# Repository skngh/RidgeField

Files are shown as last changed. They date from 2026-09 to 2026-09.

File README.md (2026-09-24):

# Ridge Field

Fully wireless guitar pedal. A small box mounts on the guitar and sends its knobs, joystick and light sensor over Bluetooth to the pedal on the floor, which runs everything and does processing through a Daisy Seed.

**[Full video walking through the pedal!](https://youtu.be/8Uf5aeJEN9k)**

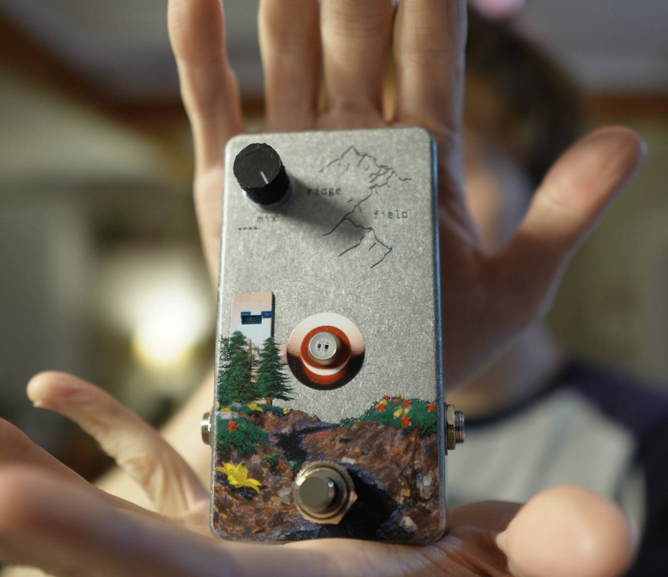
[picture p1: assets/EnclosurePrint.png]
Ridge Field pedal


Everything here is free to use!! Please let me know if you make anything with something here, I'd really love to see :)

## Contents

- [`hardware/`](hardware/): KiCad projects for both boards, custom libraries, and ready-to-order PCBWay files
- [`firmware/`](firmware/): all the code
  - [`firmware/daisy/`](firmware/daisy/): the audio DSP running on the Daisy Seed in the pedal
  - [`firmware/ESP32C3/`](firmware/ESP32C3/): the Bluetooth link (guitar-side server and pedal-side client)
- [`enclosure/`](enclosure/): FreeCAD models, STLs, and the Tayda drill template

## How it works

There are two units:

- **Server (on the guitar):** a XIAO ESP32-C3 reads the two knobs, an LDR (light sensor) and a joystick, then sends any changes over BLE. It runs off a Li-ion battery.
- **Main/Client (the pedal):** a second XIAO ESP32-C3 connects to the server and passes the control values to a Daisy Seed over UART. Then the Daisy does all the audio processing.

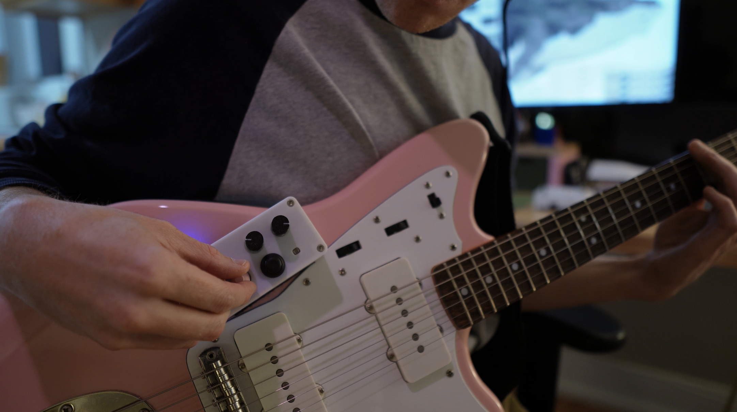
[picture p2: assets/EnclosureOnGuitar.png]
On the guitar


## Controls

| Control | What it does |
| --- | --- |
| Knob 1 | Delay time |
| Knob 2 | Delay feedback (fully down turns the delay off) |
| LDR | Reverb. Cover it with your hand for more |
| Joystick X | Pitch shift, an octave up or down depending on direction |
| Joystick Y | Bitcrusher. One direction lowers bit depth, the other lowers sample rate |
| Button press | Latch the current joystick position |
| Button hold | LDR calibration, see below |
| Mix knob (pedal) | Dry/wet |
| Footswitch (pedal) | Bypass |

**LDR calibration:** hold the joystick button. For the first few seconds leave the LDR uncovered. Once the LED starts blinking fast, cover it and keep holding until the LED goes back to normal (~7 s total). The pedal saves the calibration so it survives next time you unplug and replug.

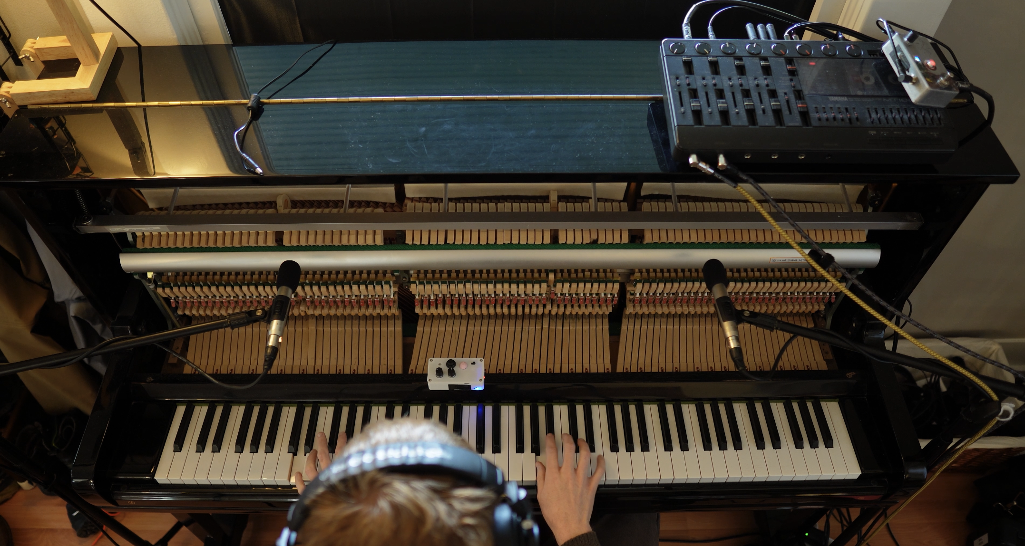
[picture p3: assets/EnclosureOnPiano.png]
On the piano


## Building one

Rough order:

1. **PCBs:** order the 2 pcbs located in [`hardware/PCBWayFiles`](hardware/PCBWayFiles/) (Gerbers, BOM and pick-and-place are all there).
2. **Server Enclosure:** 3D print the parts in [`enclosure/STL files`](enclosure/STL%20files/). Uses [M3x6mm screws](https://www.amazon.com/dp/B0DJQG5YLF?ref_=ppx_hzsearch_conn_dt_b_fed_asin_title_2) and [M3 heat inserts](https://www.amazon.com/dp/B08BCRZZS3).
3. **Main Enclosure:** the main enclosure is a 1590B pedal. I used [Tayda Electronics](https://www.taydaelectronics.com/1590b-style-aluminum-diecast-enclosure.html) for mine so I could order it fully drilled and with a UV print. Here's the [Tayda drill template](enclosure/Tayda_Drill_Schematic.txt).
4. **Firmware:** flash both ESP32-C3s from [`firmware/ESP32C3`](firmware/ESP32C3/), then build and flash the Daisy from [`firmware/daisy`](firmware/daisy/).

See each folder's README for more details.

## The artwork

I got the art on the enclosure UV printed through Tayda. The art isn't included in this repo, but here's how I did it in Blender!

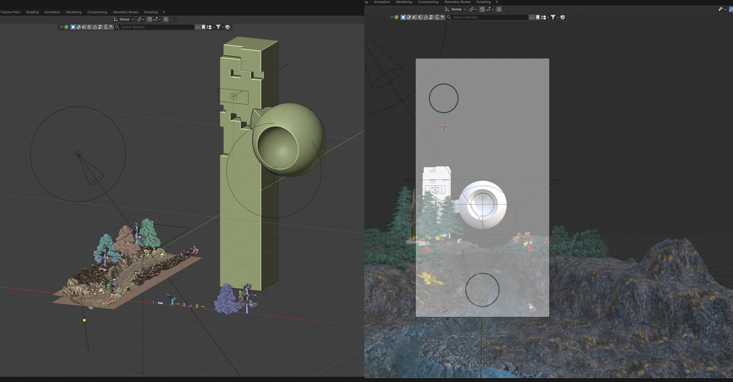
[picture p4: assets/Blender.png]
Blender scene


You can attach an image as a background to a camera in Blender. So I took the drill schematic coords and made an illustrator file showing the holes that I added as the background. Then I could easily place objects in the scene and it would line up later with the pedal (for some reason the bluetooth LED on the left didn't line up perfectly, so I think I must've gotten the coords off a tiny bit).

I have a video [here](https://www.youtube.com/watch?v=Ckmy4d0Q_N0&t=555s) showing how to make designs for Tayda's UV printing service.

## Clone it

The DSP library I used is a git submodule, so clone with:

```sh
git clone --recursive https://github.com/skngh/RidgeField.git
# if you already cloned it:
git submodule update --init
```

## Caveats

As I mentioned in the video, I am actually planning on making a V2 of the main pedal PCB going forward. It is fully functioning, but you can hear some of the data transfers as these consistent beeps going, and I'm an idiot who didn't add a LPF to the output buffer, so there's lots of high frequency noise. It's far above the range of human hearing, but I had this issue in the past where some annoying looper pedal folded that range down and caused all this aliasing (at least I think that's what happened), so I plan on making the board 4 layers and then adding a LPF across the output buffer's op amp. Relatively easy, but in order to test I'd have to reorder the boards and I don't really wanna spend that money right now :o

## Built with

- [Daisy Seed](https://electro-smith.com/products/daisy-seed) + [libDaisy](https://github.com/electro-smith/libDaisy) / [DaisySP](https://github.com/electro-smith/DaisySP)
- [Seeed XIAO ESP32-C3](https://wiki.seeedstudio.com/XIAO_ESP32C3_Getting_Started/)
- [NimBLE-Arduino](https://github.com/h2zero/NimBLE-Arduino)
- My [Simple-DSP](https://github.com/skngh/Simple-DSP) library
- KiCad 10.0, FreeCAD 1.1, Blender

## License

[MIT](LICENSE). Do whatever you want with it!

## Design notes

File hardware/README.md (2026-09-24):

# Hardware

Made with **KiCad 10.0**. Older versions won't open these files.

- [`BluetoothPedal_Main/`](BluetoothPedal_Main/): the main pedal board. Includes the Daisy, XIAO ESP32-C3, input/output buffers, DC power, footswitch and mix knob.
- [`BluetoothPedal_Server/`](BluetoothPedal_Server/): the guitar-mounted board. XIAO ESP32-C3, MCP3208 ADC, knobs, LDR, joystick, battery.
- [`libs/`](libs/): custom symbols, footprints and 3D models used by both projects
- [`PCBWayFiles/`](PCBWayFiles/): Gerbers, BOM and pick-and-place (`-all-pos.csv`) for each board. If you just want boards, these are all you need.

## Opening the projects

I think both projects should open and look right without any setup? But if you want to edit or update parts you may need to do these steps below:

- **Footprints:** each project has an `fp-lib-table` pointing to `../libs/footprints/Custom_Footprints.pretty`. This originally was an absolute path that I changed, but I'm not totally positive that works so you may need to change it, idk.
- **Symbols:** `custom_symbols` and `Seeed_Studio_XIAO_Series` aren't registered in a project symbol table. If you need them, add `libs/symbols/*.kicad_sym` under _Preferences → Manage Symbol Libraries → Project Specific Libraries_.
- **3D models:** some models seem to be absolute paths from my computer, so you may need to configure them in each footprint's settings.

None of this affects the Gerbers, those should all work fine.

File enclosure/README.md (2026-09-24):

# Enclosure

Models made with **FreeCAD 1.1**.

- [`FreeCAD files/`](FreeCAD%20files/): source models for the Main and Server enclosures, knob cap and joystick cap
- [`STL files/`](STL%20files/): ready to print
  - `Server/`: body and lid for the guitar mounted box
  - `Main/`: body and lid for the Main pedal box. I used this to make sure my drill schematic worked, and to mockup the UV print, so I just figured I'd include it.
  - `Knob/`: knob body and marker thing. I print the body in black and marker in white using a 0.2 nozzle with my Bambu Lab A1 printer (0.4 is prob fine though). I also like printing with fuzzy skin.
  - `Joystick_Cap.stl`
- [`Tayda_Drill_Schematic.txt`](Tayda_Drill_Schematic.txt): drill template to use with Tayda Electronics, or any drilling service.

## Tayda drill template

The text file can be used with Tayda's [custom drilling tool](https://drill.taydakits.com/) for a 1590B enclosure. <br>
The columns go: **Diameter, X, Y**.

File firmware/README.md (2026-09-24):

# Firmware

- [`daisy/`](daisy/): the audio side. Runs on the Daisy Seed inside the pedal and does all the effects.
- [`ESP32C3/`](ESP32C3/): the Bluetooth side. One sketch for the guitar mounted box (server), one for the pedal (client).

The client ESP32 forwards control data to the Daisy over UART at 115200 baud as a 14-byte frame. The frame format is documented at the top of `pedal_client.ino` and in `daisy/bt_link.h`.

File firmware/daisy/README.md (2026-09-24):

# Daisy firmware

The DSP for the pedal, running on a Daisy Seed.

- `BTPedal.cpp`: main program, with the effects chain, controls, bypass, LED and LDR calibration
- `bt_link.cpp` / `bt_link.h`: receives control data from the ESP32 over UART (USART1, DMA)
- `Simple-DSP/`: my DSP library (git submodule), where the reverb, bitcrusher, pitch shifter, delay and distortion come from
- `Moorer Reverb Presentation.pdf`: this is the reverb algorithm I used

Signal chain: delay → pitch shift → bitcrusher → reverb (with soft clip) → dry/wet mix.

## Before you build: set your libDaisy / DaisySP paths

The Makefile expects libDaisy and DaisySP to sit two folders up from this one:

```make
LIBDAISY_DIR = ../../libDaisy/
DAISYSP_DIR = ../../DaisySP/
```

**You must either change those two lines to point to where you have [libDaisy](https://github.com/electro-smith/libDaisy) and [DaisySP](https://github.com/electro-smith/DaisySP), or simply copy this folder to something like a MyProjects folder in your libDaisy folder.** If you end up changing the path then you'll wanna change the paths in `c_cpp_properties.json` and `tasks.json` too if you use VS Code.

Also make sure the submodule is pulled, or you'll get missing `Simple-DSP` headers:

```sh
git submodule update --init
```

## Building and flashing

You'll need the Daisy toolchain. Follow Electro-Smith's [getting started guide](https://daisy.audio/tutorials/cpp-dev-env/) if you haven't set it up.

## Pins

| Daisy pin | Use |
| --- | --- |
| D14 / pin 15 (USART1 RX) | from ESP32 TX |
| D15 | status LED |
| D16 | bypass footswitch |
| A10 | mix knob |

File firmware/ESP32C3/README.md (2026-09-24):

# ESP32-C3 firmware

Here's the 2 Arduino sketches, both for the Seeed XIAO ESP32-C3.

- [`pedal_server/`](pedal_server/): goes on the **guitar unit**. Reads the knobs and LDR (through an MCP3208 ADC), plus the joystick and its button. Advertises over BLE and notifies whenever something changes. Also handles the battery level LED.
- [`pedal_client/`](pedal_client/): goes in the **pedal**. Finds the server, subscribes to every control, and forwards them to the Daisy over UART.

Pin maps are at the top of each sketch.

## Setup

1. Install the ESP32 boards package in Arduino IDE (Espressif, via Boards Manager) and pick **XIAO_ESP32C3**.
2. Install **NimBLE-Arduino** from the Library Manager. The sketches use the 2.x API, so 1.x won't compile.
3. Flash `pedal_server` onto the guitar unit and `pedal_client` onto the pedal.

The two find each other by the service UUID and device name (`"Pedal"`). If you build more than one for some reason lol, or want to avoid interference with someone else's (since everyone and their mom will have one soon), change `SERVICE_UUID` / `DEVICE_NAME` and the characteristic UUIDs to match in **both** sketches.

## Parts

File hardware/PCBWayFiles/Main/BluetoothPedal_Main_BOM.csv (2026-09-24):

Reference | Qty | Manufacturer | MPN | DNP | Package
A1 | 1 |  |  | DNP
C1 | 1 | YAGEO | CC0805JRNPO9BN101 |  | 0805 (2012 Metric)
C2 | 1 | YAGEO | CC0805JRNPO9BN102 |  | 0805 (2012 Metric)
C3,C4,C5 | 3 | YAGEO | CC0805KKX7R8BB105 |  | 0805 (2012 Metric)
C6,C8,C10 | 3 | YAGEO | CC0805MKX5R8BB226 |  | 0805 (2012 Metric)
C7,C11,C12 | 3 | KEMET | C0805C104K5RACTU |  | 0805 (2012 Metric)
C9 | 1 | YAGEO | CC0805KKX5R8BB106 |  | 0805 (2012 Metric)
D1 | 1 | onsemi | SS14 |  | DO-214AC, SMA
D2,D3 | 2 |  |  | DNP
FB1 | 1 | Murata Electronics | BLM21PG600SN1D |  | 0805 (2012 Metric)
J1,J2 | 2 |  |  | DNP
J3 | 1 |  |  | DNP
L1 | 1 | Coilcraft | XFL3012-222MEC |  | 1212 (3030 Metric)
R1,R11,R12 | 3 | YAGEO | RC0805FR-071KL |  | 0805 (2012 Metric)
R2,R3,R4,R5 | 4 | YAGEO | RC0805FR-071ML |  | 0805 (2012 Metric)
R6,R8 | 2 | YAGEO | RC0805FR-07100KL |  | 0805 (2012 Metric)
R7 | 1 | YAGEO | RC0805FR-07100RL |  | 0805 (2012 Metric)
RV1 | 1 |  |  | DNP
SW1 | 1 |  |  | DNP
TP1,TP2,TP3,TP4 | 4 |  |  | DNP
U1 | 1 | Texas Instruments | TL072CDR |  | 8-SOIC (0.154", 3.90mm Width)
U2 | 1 | Texas Instruments | TPS62163DSGT |  | 8-WSON (2x2)
U3 | 1 |  |  | DNP

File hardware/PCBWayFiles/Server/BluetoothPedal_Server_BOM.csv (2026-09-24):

Reference | Qty | MANUFACTURER | MPN | DNP
C1,C2,C3 | 3 | Murata | GCM21BR71H104KA37L
C4 | 1 | Murata | GRM219R61A475KE19D
D1 | 1 |  |  | DNP
D2 | 1 |  |  | DNP
J1 | 1 |  |  | DNP
J2 | 1 |  |  | DNP
L1 | 1 |  |  | DNP
R1,R2 | 2 | Yagato | RC0805FR-07220KL
R3,R5 | 2 | Yagato | RC0805FR-071KL
R4 | 1 | Yagato | RC0805FR-0710KL
RV1,RV2 | 2 |  |  | DNP
SW1 | 1 |  |  | DNP
SW2 | 1 |  |  | DNP
TP1,TP2,TP3,TP4,TP5,TP6 | 6 |  |  | DNP
U1 | 1 | Seeed Technology |  | DNP
U2 | 1 | Microchip | MCP3208-CI/SL

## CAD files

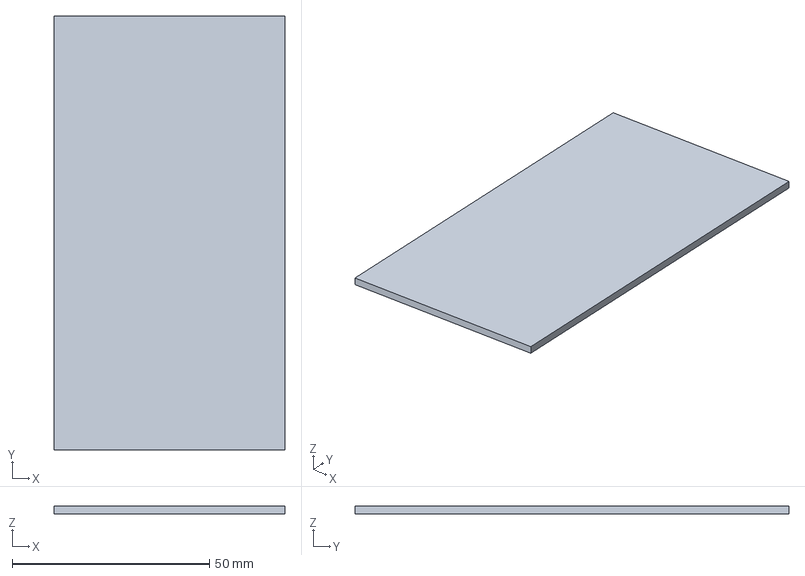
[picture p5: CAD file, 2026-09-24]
enclosure/FreeCAD files/BT_Pedal_main.FCStd
58.5 x 110.0 x 2.00 mm

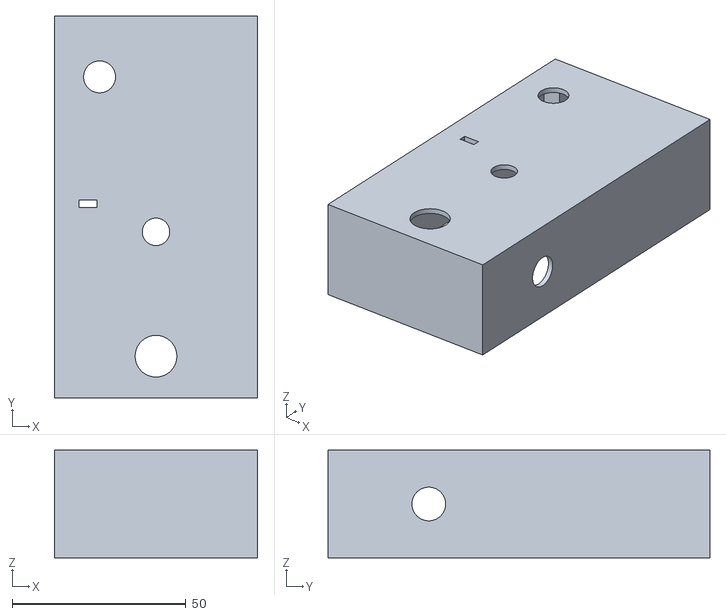
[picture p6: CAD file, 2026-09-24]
enclosure/STL files/Main/main-Body.stl
58.5 x 110.0 x 31.0

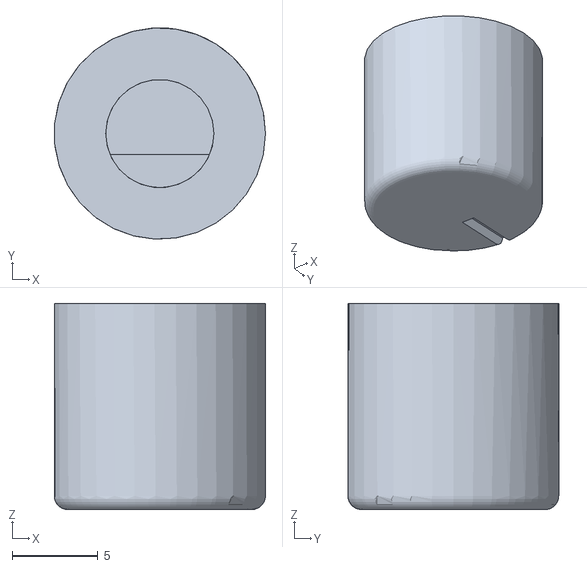
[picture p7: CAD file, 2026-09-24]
enclosure/STL files/Knob/Knob_Body.stl
12.3 x 12.3 x 12.0

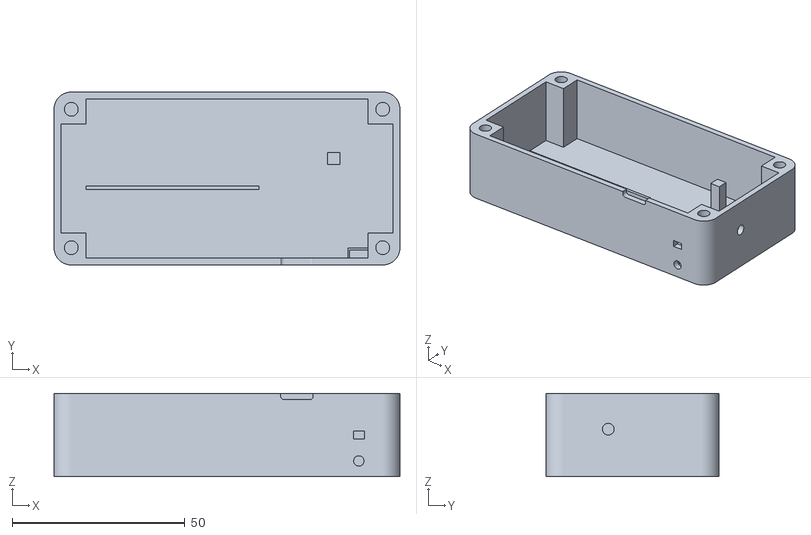
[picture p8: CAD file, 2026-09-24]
enclosure/STL files/Server/Server-Body.stl
100.0 x 50.0 x 24.0

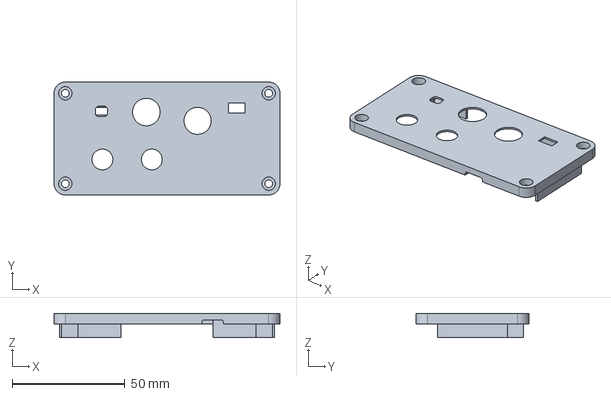
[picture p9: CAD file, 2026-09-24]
enclosure/FreeCAD files/BT_Pedal_server.FCStd
100.0 x 50.0 x 10.8 mm

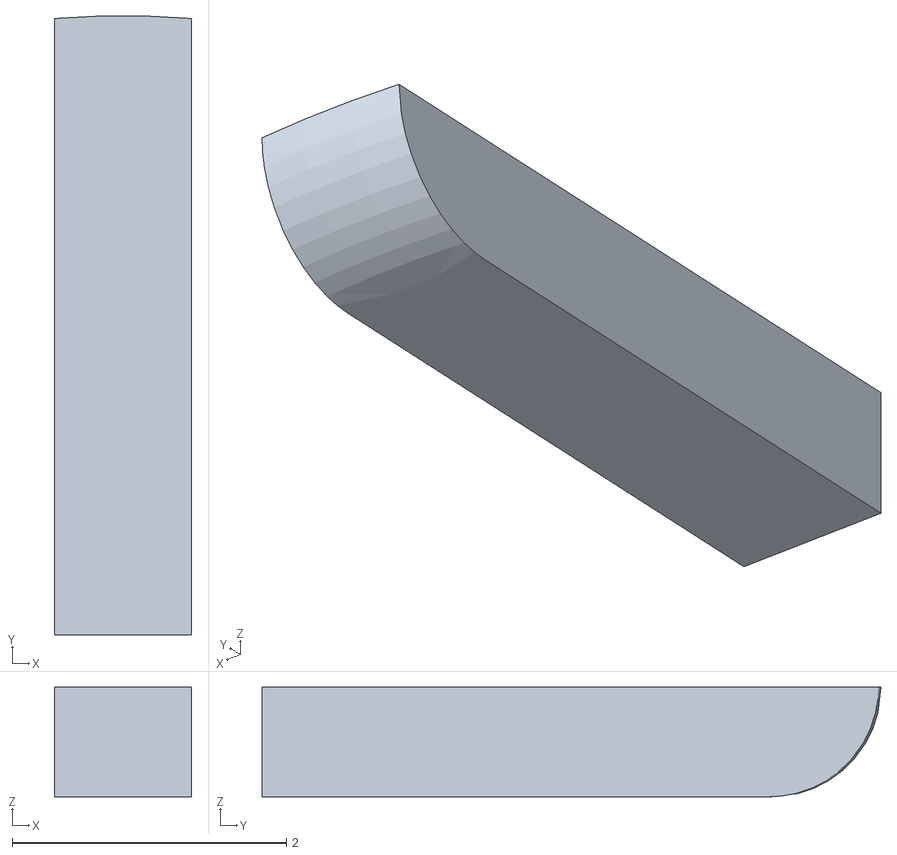
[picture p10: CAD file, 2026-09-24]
enclosure/STL files/Knob/Knob_Tab.stl
1.00 x 4.52 x 0.8

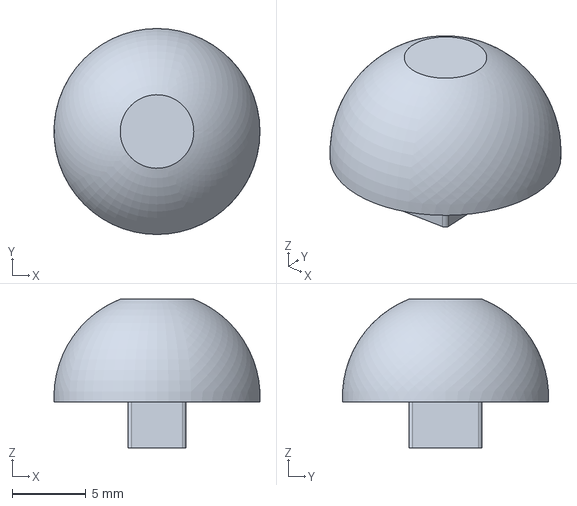
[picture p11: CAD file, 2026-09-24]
enclosure/FreeCAD files/Joystick_Cap.FCStd
14.0 x 14.0 x 10.1 mm

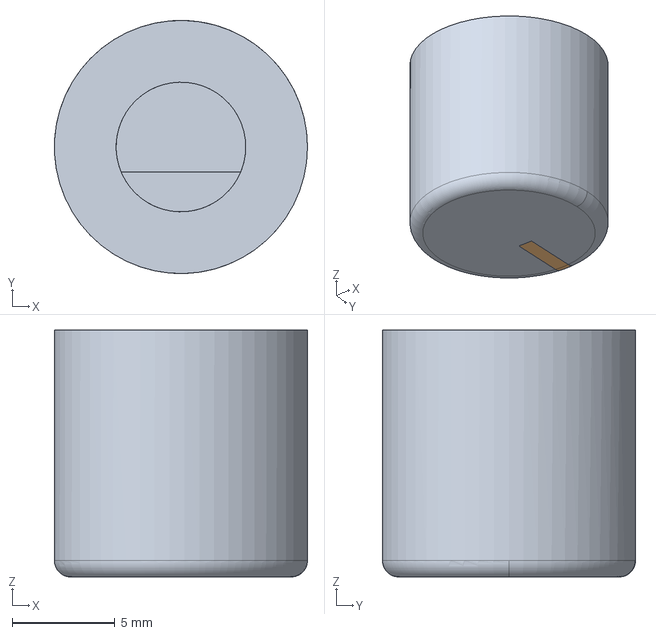
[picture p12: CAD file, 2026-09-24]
enclosure/FreeCAD files/KnobCap.FCStd
12.3 x 12.3 x 12.0 mm
Knob
KnobTab

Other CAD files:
enclosure/STL files/Main/main-Lid.stl
enclosure/STL files/Server/Server-Lid.stl
enclosure/STL files/Joystick_Cap.stl

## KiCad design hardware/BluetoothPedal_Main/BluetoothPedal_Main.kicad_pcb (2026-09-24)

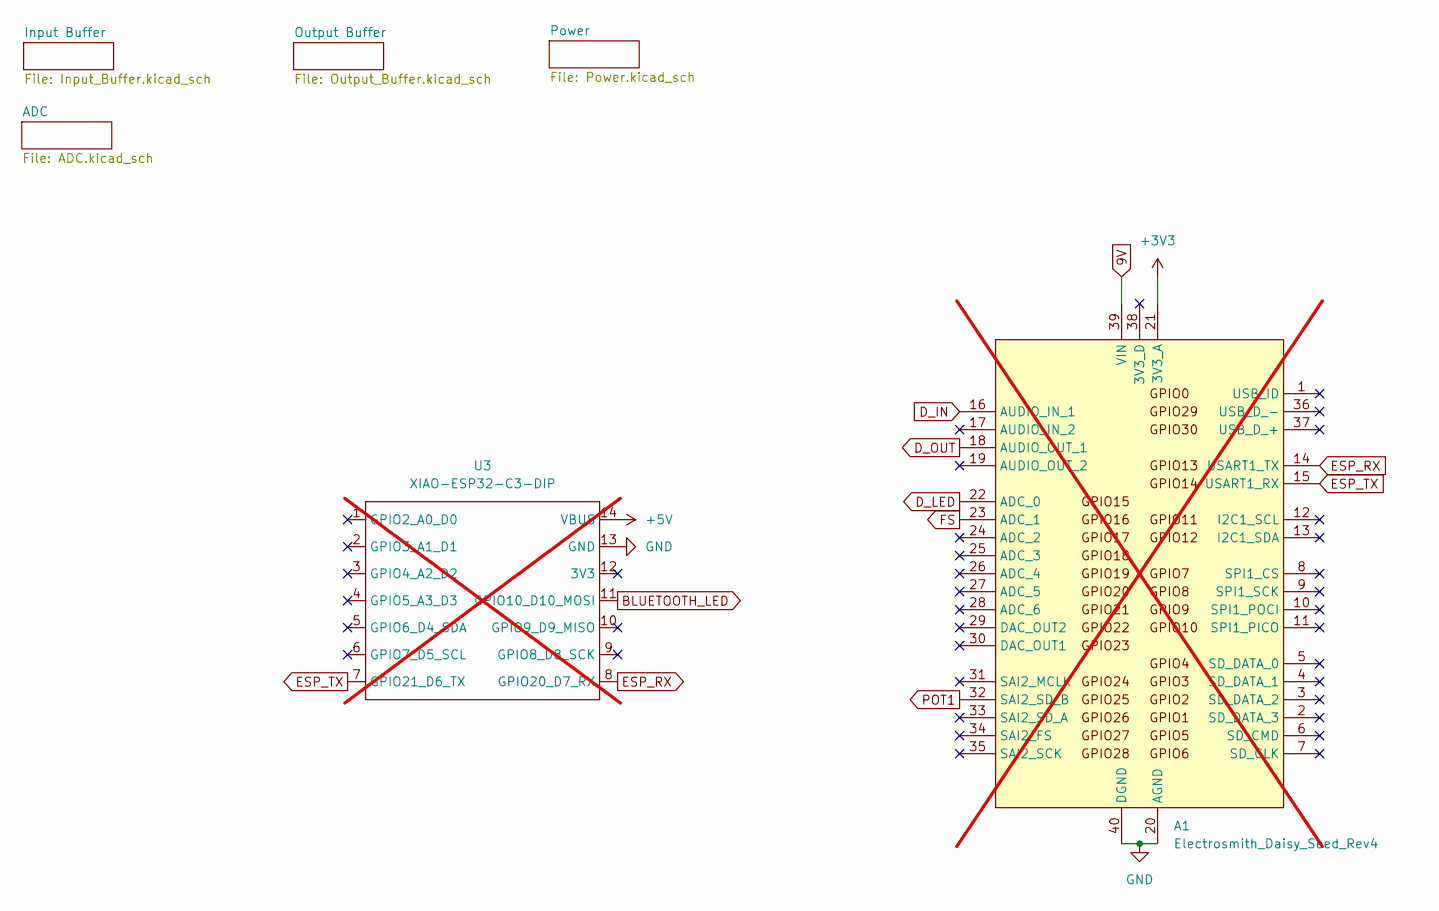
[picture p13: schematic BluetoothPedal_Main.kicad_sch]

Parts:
A1: Electrosmith_Daisy_Seed_Rev4; Electrosmith_Daisy_Seed; not fitted
U3: XIAO-ESP32-C3-DIP; not fitted

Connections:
9V: A1.39 (VIN); also elsewhere on the board
+3V3: A1.21 (3V3_A); also elsewhere on the board
+5V: U3.14 (VBUS); also elsewhere on the board
BLUETOOTH_LED: U3.11 (GPIO10_D10_MOSI); also elsewhere on the board
D_IN: A1.16 (AUDIO_IN_1); also elsewhere on the board
D_LED: A1.22 (ADC_0); also elsewhere on the board
D_OUT: A1.18 (AUDIO_OUT_1); also elsewhere on the board
ESP_RX: A1.14 (USART1_TX), U3.8 (GPIO20_D7_RX)
ESP_TX: A1.15 (USART1_RX), U3.7 (GPIO21_D6_TX)
FS: A1.23 (ADC_1); also elsewhere on the board
GND: A1.20 (AGND), A1.40 (DGND), U3.13 (GND); also elsewhere on the board
POT1: A1.32 (SAI2_SD_B); also elsewhere on the board

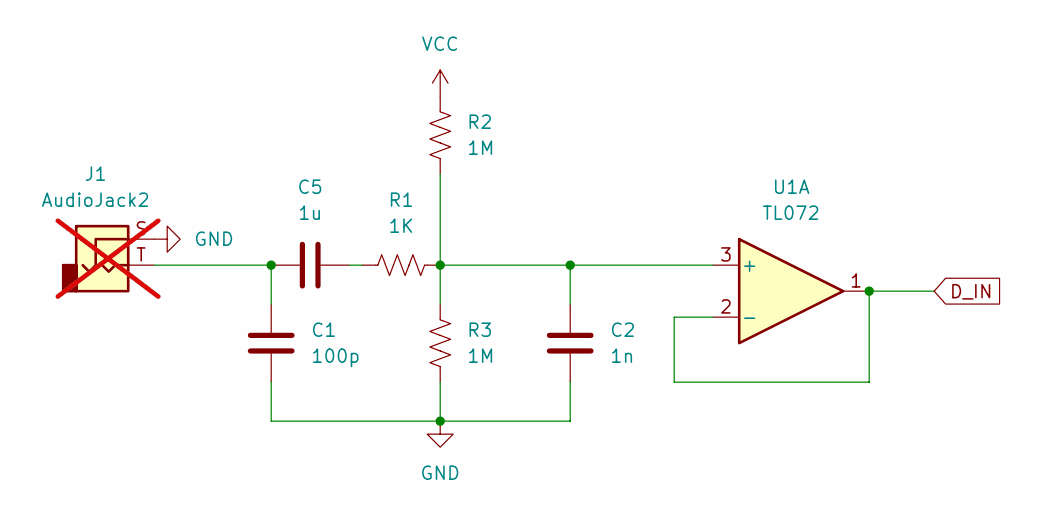
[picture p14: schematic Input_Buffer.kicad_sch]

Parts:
C1: 100p; C_0805_2012Metric; MPN CC0805JRNPO9BN101
C2: 1n; C_0805_2012Metric; MPN CC0805JRNPO9BN102
C5: 1u; C_0805_2012Metric; MPN CC0805KKX7R8BB105
J1: AudioJack2; SolderWire-0.5sqmm_1x02_P4.6mm_D0.9mm_OD2.1mm; not fitted
R1: 1K; R_0805_2012Metric; MPN RC0805FR-071KL
R2, R3: 1M; R_0805_2012Metric; MPN RC0805FR-071ML
U1: TL072; SOIC-8_3.9x4.9mm_P1.27mm; MPN TL072CDR

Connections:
D_IN: U1.1, U1.2 (-); also elsewhere on the board
GND: C1.2, C2.2, J1.S, R3.1; also elsewhere on the board
unnamed: C1.1, C5.2, J1.T
unnamed: C5.1, R1.1
unnamed: C2.1, R1.2, R2.1, R3.2, U1.3 (+)
VCC: R2.2; also elsewhere on the board

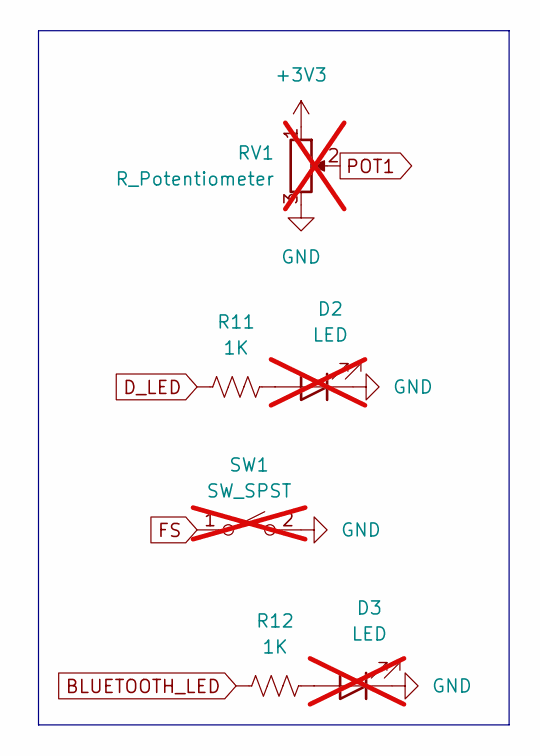
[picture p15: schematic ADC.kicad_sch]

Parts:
D2: LED; LED_D5.0mm; not fitted
D3: LED; LED_Rectangular_W5.0mm_H2.0mm; not fitted
R11, R12: 1K; R_0805_2012Metric; MPN RC0805FR-071KL
RV1: R_Potentiometer; RV11114NO; not fitted
SW1: SW_SPST; SolderWire-0.5sqmm_1x02_P4.6mm_D0.9mm_OD2.1mm; not fitted

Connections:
+3V3: RV1.1; also elsewhere on the board
BLUETOOTH_LED: R12.1; also elsewhere on the board
D_LED: R11.1; also elsewhere on the board
FS: SW1.1 (A); also elsewhere on the board
GND: D2.1 (K), D3.1 (K), RV1.3, SW1.2 (B); also elsewhere on the board
unnamed: D2.2 (A), R11.2
unnamed: D3.2 (A), R12.2
POT1: RV1.2; also elsewhere on the board

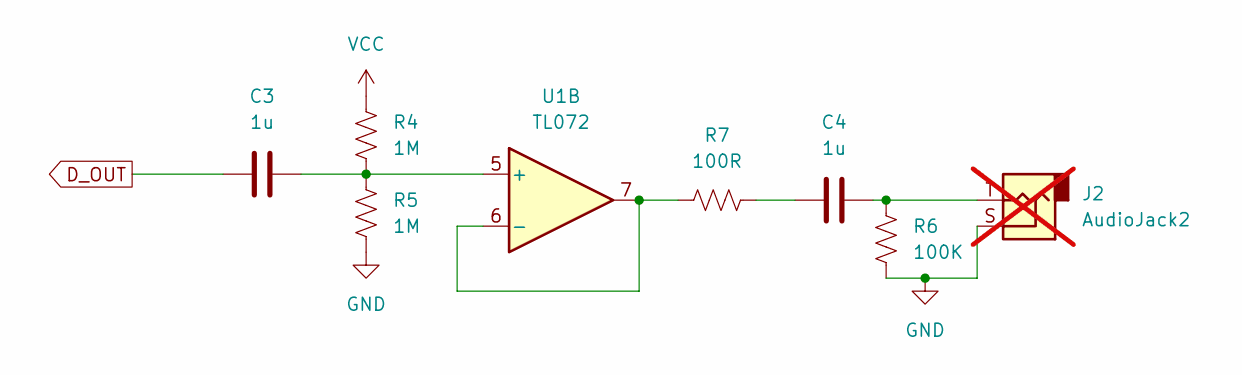
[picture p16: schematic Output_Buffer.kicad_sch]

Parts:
C3, C4: 1u; C_0805_2012Metric; MPN CC0805KKX7R8BB105
J2: AudioJack2; SolderWire-0.5sqmm_1x02_P4.6mm_D0.9mm_OD2.1mm; not fitted
R4, R5: 1M; R_0805_2012Metric; MPN RC0805FR-071ML
R6: 100K; R_0805_2012Metric; MPN RC0805FR-07100KL
R7: 100R; R_0805_2012Metric; MPN RC0805FR-07100RL
U1: TL072; SOIC-8_3.9x4.9mm_P1.27mm; MPN TL072CDR

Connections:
D_OUT: C3.1; also elsewhere on the board
GND: J2.S, R5.2, R6.2; also elsewhere on the board
unnamed: C4.1, R7.2
unnamed: C4.2, J2.T, R6.1
unnamed: C3.2, R4.2, R5.1, U1.5 (+)
unnamed: R7.1, U1.6 (-), U1.7
VCC: R4.1; also elsewhere on the board

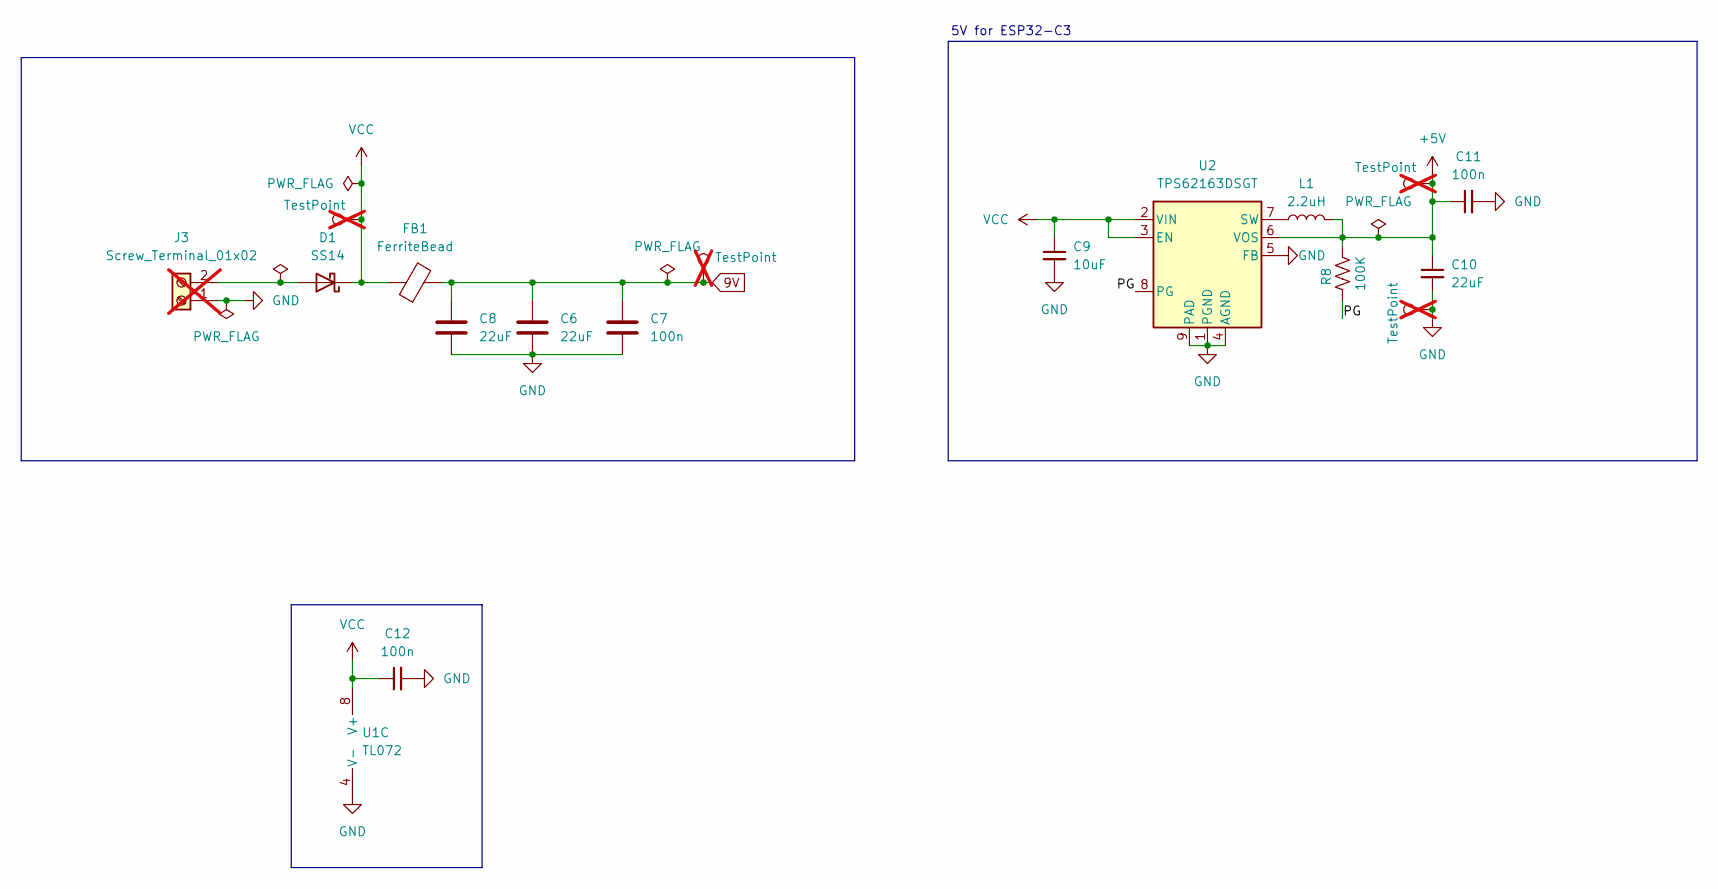
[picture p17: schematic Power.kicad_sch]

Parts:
C6, C8, C10: 22uF; C_0805_2012Metric; MPN CC0805MKX5R8BB226
C7, C11, C12: 100n; C_0805_2012Metric; MPN C0805C104K5RACTU
C9: 10uF; C_0805_2012Metric; MPN CC0805KKX5R8BB106
D1: SS14; D_SMA; MPN SS14
FB1: FerriteBead; L_0805_2012Metric; MPN BLM21PG600SN1D
J3: Screw_Terminal_01x02; Screw Terminal 1x2 5mm; not fitted
L1: 2.2uH; Coilcraft_XFL3012; MPN XFL3012-222MEC
R8: 100K; R_0805_2012Metric; MPN RC0805FR-07100KL
TP1, TP2, TP3, TP4: TestPoint; TestPoint_Pad_D2.0mm; not fitted
U1: TL072; SOIC-8_3.9x4.9mm_P1.27mm; MPN TL072CDR
U2: TPS62163DSGT; WSON-8-1EP_2x2mm_P0.5mm_EP0.9x1.6mm_ThermalVias; MPN TPS62163DSGT

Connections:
9V: C6.1, C7.1, C8.1, FB1.2, TP2.1 (1_1); also elsewhere on the board
+5V: C10.1, C11.1, L1.2, R8.2, TP1.1 (1_1), U2.6 (VOS); also elsewhere on the board
/Power/PG: R8.1, U2.8 (PG)
GND: C6.2, C7.2, C8.2, C9.2, C10.2, C11.2, C12.2, J3.1, TP4.1 (1_1), U1.4 (V-), U2.1 (PGND), U2.4 (AGND), U2.5 (FB), U2.9 (PAD); also elsewhere on the board
unnamed: D1.2 (A), J3.2
unnamed: L1.1, U2.7 (SW)
VCC: C9.1, C12.1, D1.1 (K), FB1.1, TP3.1 (1_1), U1.8 (V+), U2.2 (VIN), U2.3 (EN); also elsewhere on the board

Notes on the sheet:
5V for ESP32-C3

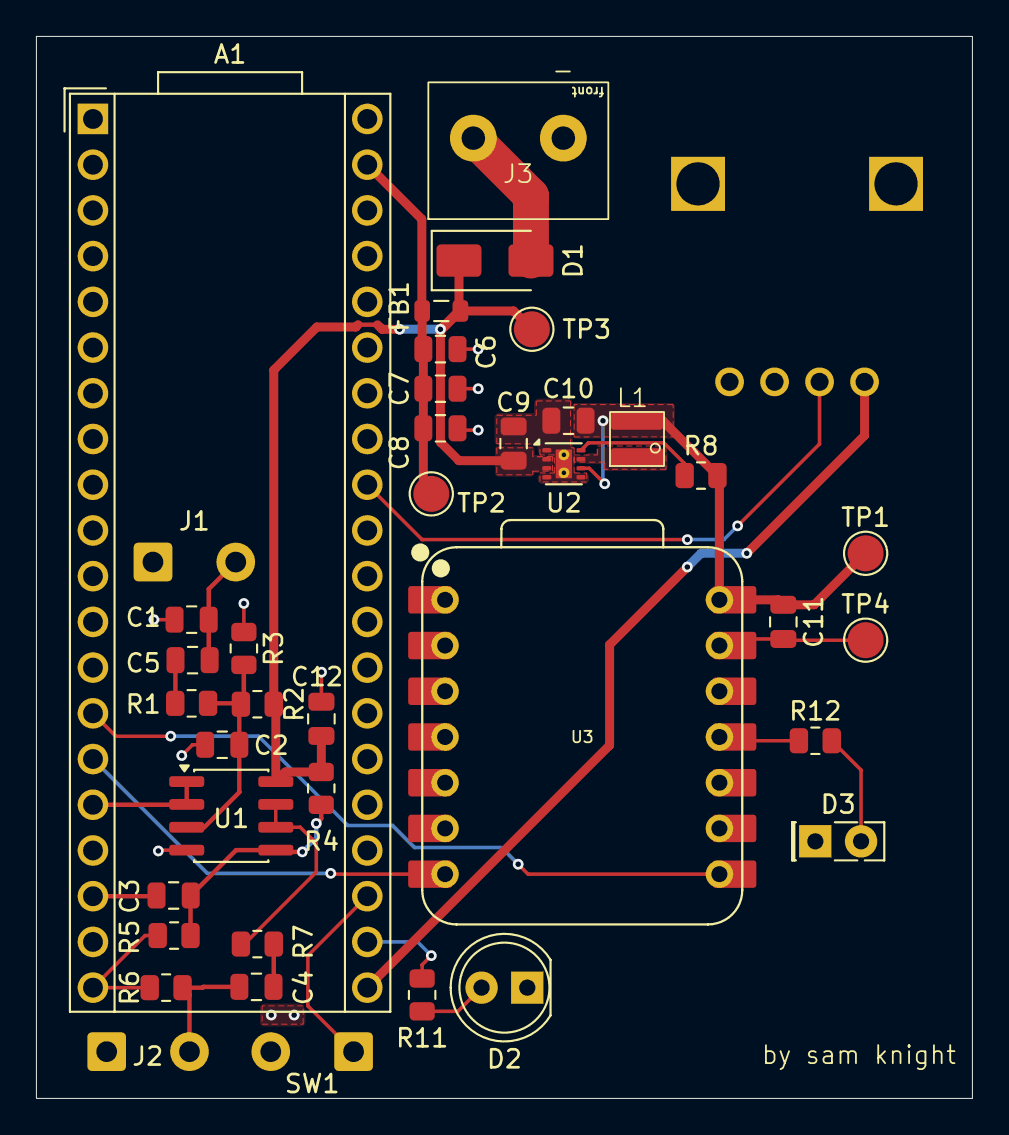
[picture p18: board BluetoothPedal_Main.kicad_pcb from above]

Board: 2 copper layers, 52.0 x 59.0 mm, 40 parts (1 on the bottom side), 25 nets.

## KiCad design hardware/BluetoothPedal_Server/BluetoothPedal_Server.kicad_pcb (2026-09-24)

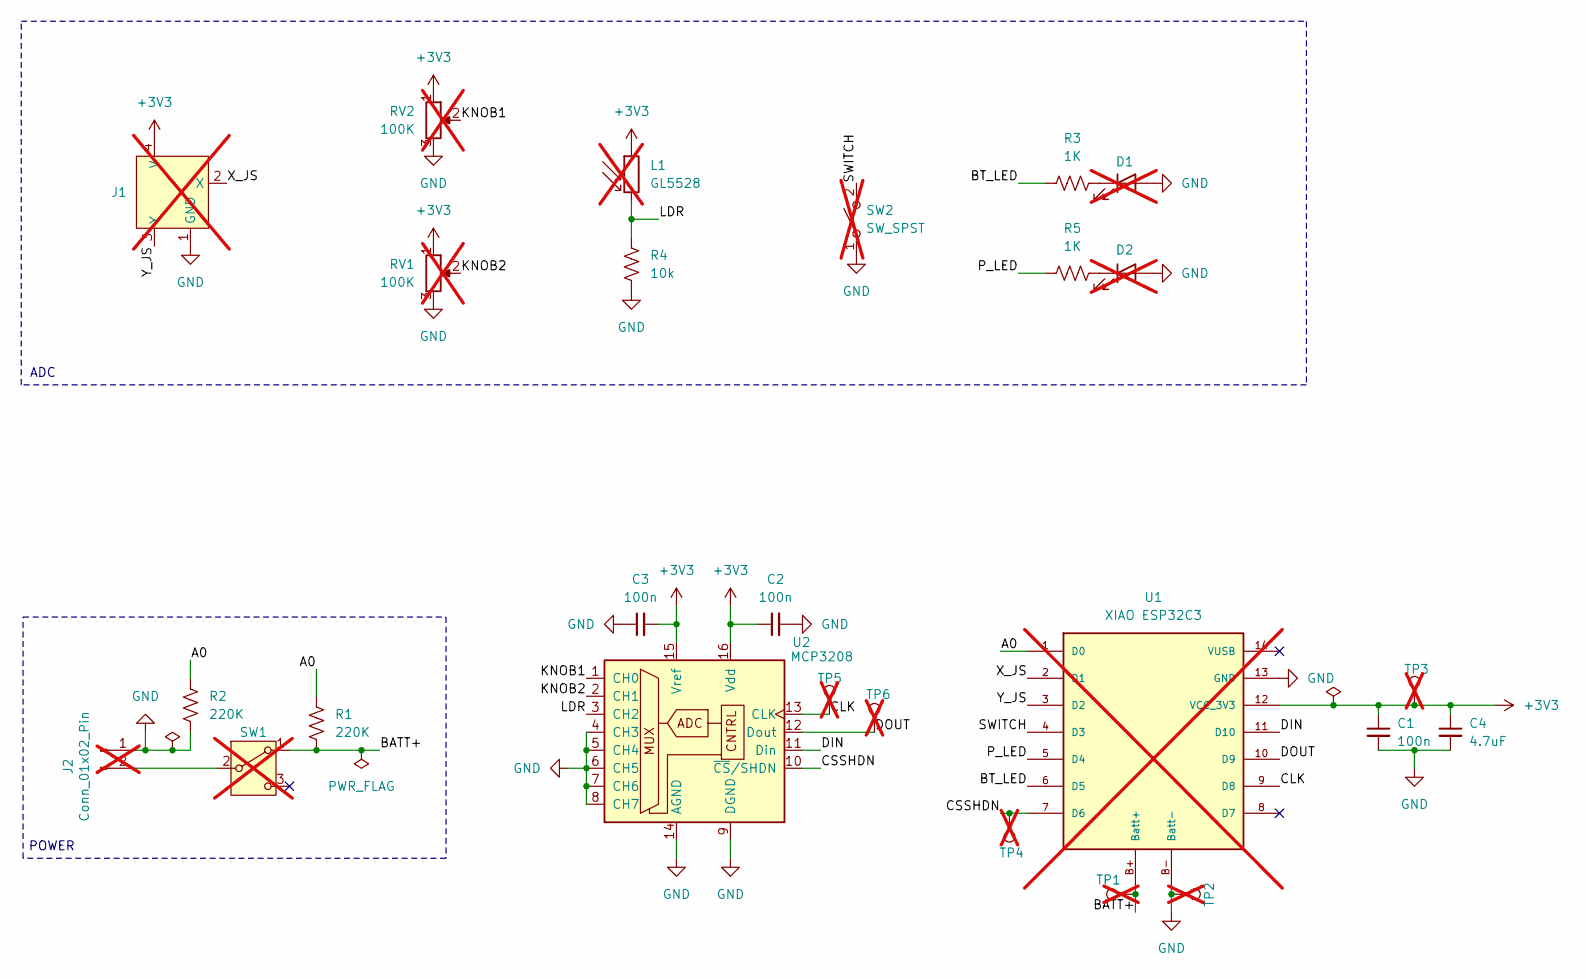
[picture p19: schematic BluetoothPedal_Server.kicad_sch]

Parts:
C1, C2, C3: 100n; C_0805_2012Metric; MPN GCM21BR71H104KA37L
C4: 4.7uF; C_0805_2012Metric; MPN GRM219R61A475KE19D
D1: LED_D3.0mm; not fitted
D2: LED_Rectangular_W5.0mm_H2.0mm; not fitted
J1: Mini 2-Axis Analog Thumbstick; not fitted
J2: Conn_01x02_Pin; JST_PH_S2B-PH-K_1x02_P2.00mm_Horizontal; not fitted
L1: GL5528; R_LDR_5.1x4.3mm_P3.4mm_Vertical; not fitted
R1, R2: 220K; R_0805_2012Metric; MPN RC0805FR-07220KL
R3, R5: 1K; R_0805_2012Metric; MPN RC0805FR-071KL
R4: 10k; R_0805_2012Metric; MPN RC0805FR-0710KL
RV1, RV2: 100K; RV11114NO; not fitted
SW1: SW_SPDT; Slide Switch 1P2T; not fitted
SW2: SW_SPST; SolderWire-0.5sqmm_1x02_P4.8mm_D0.9mm_OD2.3mm; not fitted
TP1, TP2, TP3, TP4, TP5, TP6: TestPoint; TestPoint_Pad_D2.0mm; not fitted
U1: XIAO ESP32C3; xiao_esp32c3; not fitted
U2: MCP3208; SOIC-16_3.9x9.9mm_P1.27mm; MPN MCP3208-CI/SL

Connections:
+3V3: C1.1, C2.1, C3.2, C4.1, J1.4 (V), L1.1, RV1.1, RV2.1, TP3.1 (1_1), U1.12 (VCC_3V3), U2.15 (Vref), U2.16 (Vdd)
/A0: R1.2, R2.1, U1.1 (D0)
/BATT+: R1.1, SW1.1 (A), TP1.1 (1_1), U1.B+ (Batt+)
/BT_LED: R3.1, U1.6 (D5)
/CLK: TP5.1 (1_1), U1.9 (D8), U2.13 (CLK)
/CSSHDN: TP4.1 (1_1), U1.7 (D6), U2.10 (~CS/SHDN)
/DIN: U1.11 (D10), U2.11 (Din)
/DOUT: TP6.1 (1_1), U1.10 (D9), U2.12 (Dout)
/KNOB1: RV2.2, U2.1 (CH0)
/KNOB2: RV1.2, U2.2 (CH1)
/LDR: L1.2, R4.1, U2.3 (CH2)
/P_LED: R5.1, U1.5 (D4)
/SWITCH: SW2.2 (B), U1.4 (D3)
/X_JS: J1.2 (X), U1.2 (D1)
/Y_JS: J1.3 (Y), U1.3 (D2)
GND: C1.2, C2.2, C3.1, C4.2, D1.2 (A), D2.2 (A), J1.1 (GND), J2.1, R2.2, R4.2, RV1.3, RV2.3, SW2.1 (A), TP2.1 (1_1), U1.13 (GND), U1.B- (Batt-), U2.4 (CH3), U2.5 (CH4), U2.6 (CH5), U2.7 (CH6), U2.8 (CH7), U2.9 (DGND), U2.14 (AGND)
unnamed: D1.1 (K), R3.2
unnamed: D2.1 (K), R5.2
unnamed: J2.2, SW1.2 (B)

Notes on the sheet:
POWER
ADC

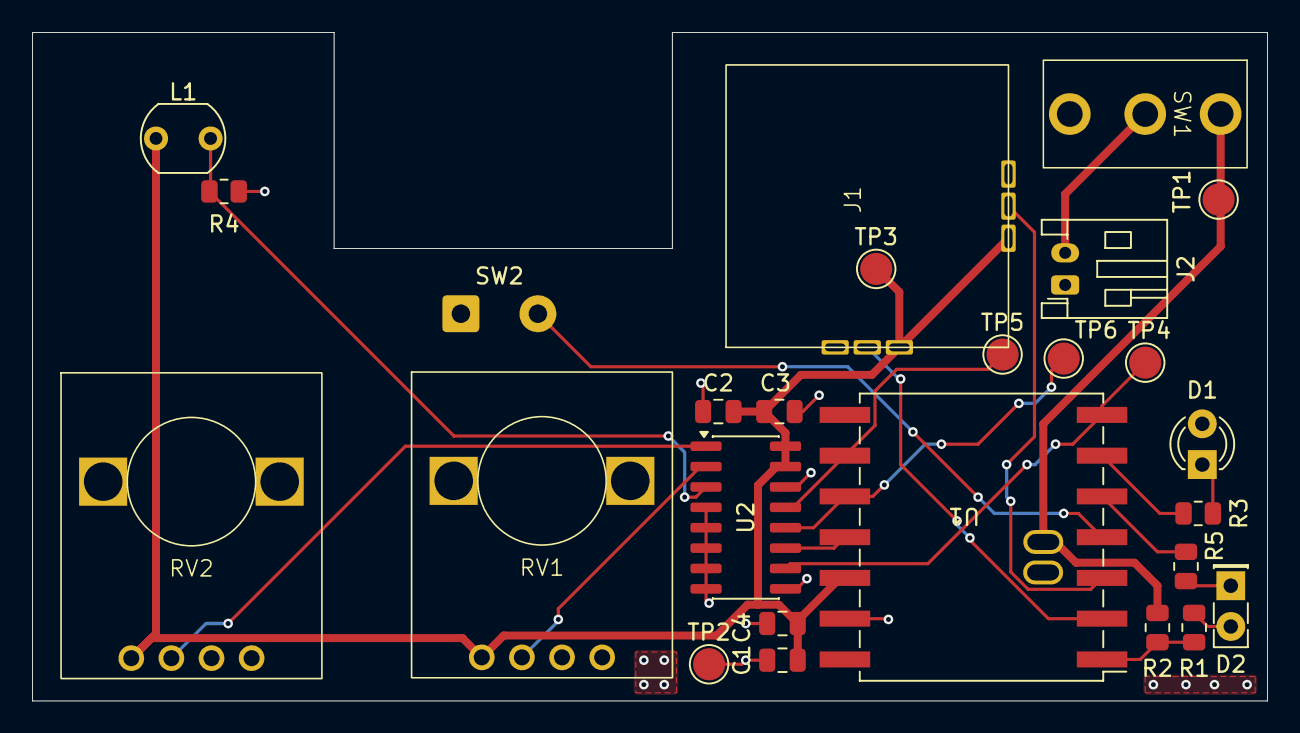
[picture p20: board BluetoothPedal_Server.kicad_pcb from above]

Board: 2 copper layers, 77.0 x 41.7 mm, 26 parts (0 on the bottom side), 19 nets.

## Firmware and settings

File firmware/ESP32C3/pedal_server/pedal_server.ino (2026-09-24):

// BLE server — runs on the guitar/handheld unit (XIAO ESP32-C3)
// Reads the controls and notifies the connected client on change.
//
// Control sources:
//   Knob1 / Knob2 / LDR  -> MCP3208 external ADC (CH0 / CH1 / CH2) over SPI
//   Joystick X / Y       -> XIAO on-board ADC (D1 / D2)
//   Switch               -> joystick push-button (D3, digital, active-low)
//
// Pin map (XIAO ESP32-C3, server side):
//   D0  / GPIO2   A0           battery sense (via divider — see BATT_* below)
//   D1  / GPIO3   Joystick X   (ADC)
//   D2  / GPIO4   Joystick Y   (ADC)
//   D3  / GPIO5   Switch       (digital, INPUT_PULLUP)
//   D4  / GPIO6   BT_LED       connection status (blinks advertising, solid connected)
//   D5  / GPIO7   P_LED        battery status (brightness = %, blinks when low)
//   D6  / GPIO21  CS/SHDN      MCP3208 chip select
//   D8  / GPIO8   SCK          MCP3208 CLK
//   D9  / GPIO9   MISO         MCP3208 Dout
//   D10 / GPIO10  MOSI         MCP3208 Din

#include <NimBLEDevice.h>
#include <SPI.h>
#include "esp_system.h" 

// ── MCP3208 SPI pins ──────────────────────────────────────
static const uint8_t PIN_SCK  = D8;
static const uint8_t PIN_MISO = D9;
static const uint8_t PIN_MOSI = D10;
static const uint8_t PIN_CS   = D6;

static const uint32_t MCP_SPI_HZ = 1000000;

// ── Status LEDs ───────────────────────────────────────────
static const uint8_t BATT_LED_PIN = D5;   // battery status
static const uint8_t CONN_LED_PIN = D4;   // client connected

// ── Battery sense (R1/R2 = 220k/220k divider into A0) ─────
static const uint8_t BATT_ADC_PIN = D0;
static const float   BATT_DIVIDER = 2.0f;   // (R1 + R2) / R2 = (220k + 220k) / 220k
static const float   BATT_FULL_V  = 4.20f;  // 1S Li-Ion full  -> 100%
static const float   BATT_EMPTY_V = 3.30f;  // 1S Li-Ion empty -> 0%
static const float   BATT_LOW_V   = 3.45f;  // below this: blink instead of dim

// ── Control definitions ───────────────────────────────────
enum Source { SRC_MCP, SRC_ADC, SRC_DIGITAL };

struct Control {
    const char*           name;
    Source                source;
    uint8_t               channel;   // MCP channel for SRC_MCP, else GPIO pin
    const char*           uuid;
    NimBLECharacteristic* characteristic;
    uint16_t              lastValue;
};

static Control controls[] = {
    { "Knob1",  SRC_MCP,     0,  "a1b2c3d4-0001-0000-0000-000000000001", nullptr, 0 },
    { "Knob2",  SRC_MCP,     1,  "a1b2c3d4-0001-0000-0000-000000000002", nullptr, 0 },
    { "LDR",    SRC_MCP,     2,  "a1b2c3d4-0001-0000-0000-000000000003", nullptr, 0 },
    { "JoyX",   SRC_ADC,     D1, "a1b2c3d4-0001-0000-0000-000000000004", nullptr, 0 },
    { "JoyY",   SRC_ADC,     D2, "a1b2c3d4-0001-0000-0000-000000000005", nullptr, 0 },
    { "Switch", SRC_DIGITAL, D3, "a1b2c3d4-0001-0000-0000-000000000006", nullptr, 0 },
};
static const uint8_t NUM_CONTROLS = sizeof(controls) / sizeof(controls[0]);

// ── BLE config ────────────────────────────────────────────
static const char* SERVICE_UUID = "a1b2c3d4-0001-0000-0000-000000000000";
static const char* DEVICE_NAME  = "Pedal";

// ── Tuning ────────────────────────────────────────────────
static const uint16_t ADC_DEADBAND = 12;  // ignore analog noise smaller than this (0–4095)
static const uint32_t SAMPLE_MS    = 20;  // 50 Hz sample rate

// ── State ─────────────────────────────────────────────────
static NimBLEServer* bleServer = nullptr;
static bool          clientConnected = false;

// ── MCP3208 single-ended read (12-bit, 0–4095) ────────────
uint16_t readMCP3208(uint8_t channel) {
    SPI.beginTransaction(SPISettings(MCP_SPI_HZ, MSBFIRST, SPI_MODE0));
    digitalWrite(PIN_CS, LOW);
    uint8_t cmd = 0b00000110 | ((channel & 0x04) >> 2); 
    SPI.transfer(cmd);
    uint8_t hi = SPI.transfer((channel & 0x03) << 6);   
    uint8_t lo = SPI.transfer(0x00);
    digitalWrite(PIN_CS, HIGH);
    SPI.endTransaction();
    return ((hi & 0x0F) << 8) | lo;
}

uint16_t readControl(const Control& c) {
    switch (c.source) {
        case SRC_MCP:     return readMCP3208(c.channel);
        case SRC_ADC:     return analogRead(c.channel);        
        case SRC_DIGITAL: return digitalRead(c.channel) ? 0 : 1;
    }
    return 0;
}

static float readBatteryVolts() {
    return (analogReadMilliVolts(BATT_ADC_PIN) / 1000.0f) * BATT_DIVIDER;
}

static int batteryPercent(float volts) {
    int pct = (int)((volts - BATT_EMPTY_V) / (BATT_FULL_V - BATT_EMPTY_V) * 100.0f);
    return constrain(pct, 0, 100);
}

// ── Battery status LED ────────────────────────────────────
// Brightness tracks battery
void updateBatteryLed() {
    static uint32_t lastCheck = 0;
    static float    volts     = BATT_FULL_V;

    if (millis() - lastCheck > 1000) {
        lastCheck = millis();
        volts = readBatteryVolts();
        Serial.printf("Battery: %.2f V (%d%%)%s\n",
                      volts, batteryPercent(volts), volts < BATT_LOW_V ? " LOW" : "");
    }

    if (volts < BATT_LOW_V)
        analogWrite(BATT_LED_PIN, ((millis() / 250) % 2) ? 255 : 0);  // blink ~2 Hz
    else
        analogWrite(BATT_LED_PIN, map(batteryPercent(volts), 0, 100, 0, 255));
}

// Connection LED: solid when a client is connected, blinks ~2 Hz while advertising.
void updateConnLed() {
    digitalWrite(CONN_LED_PIN, clientConnected ? HIGH : ((millis() / 250) % 2));
}

// ── BLE callbacks ─────────────────────────────────────────
class ServerCallbacks : public NimBLEServerCallbacks {
    void onConnect(NimBLEServer*, NimBLEConnInfo&) override {
        clientConnected = true;   // LED handling is in updateConnLed()
        Serial.println("Client connected");
    }
    void onDisconnect(NimBLEServer*, NimBLEConnInfo&, int) override {
        clientConnected = false;
        Serial.println("Client disconnected — restarting advertising");
        NimBLEDevice::startAdvertising();
    }
};

void bootBlink() {
    for (int i = 0; i < 3; i++) {
        digitalWrite(BATT_LED_PIN, HIGH);
        digitalWrite(CONN_LED_PIN, HIGH);
        delay(120);
        digitalWrite(BATT_LED_PIN, LOW);
        digitalWrite(CONN_LED_PIN, LOW);
        delay(120);
    }
}

void setup() {
    Serial.begin(115200);
    delay(300);
    Serial.printf("\n=== Pedal server boot === reset_reason=%d %s\n",
                  esp_reset_reason(),
                  esp_reset_reason() == ESP_RST_BROWNOUT ? "(BROWNOUT! supply sagging)" : "");

    pinMode(BATT_LED_PIN, OUTPUT);
    pinMode(CONN_LED_PIN, OUTPUT);
    digitalWrite(BATT_LED_PIN, LOW);
    digitalWrite(CONN_LED_PIN, LOW);
    bootBlink(); 

    // Control inputs
    for (auto& c : controls) {
        if (c.source == SRC_ADC)          pinMode(c.channel, INPUT);
        else if (c.source == SRC_DIGITAL) pinMode(c.channel, INPUT_PULLUP);
    }

    // MCP3208 SPI
    pinMode(PIN_CS, OUTPUT);
    digitalWrite(PIN_CS, HIGH);
    SPI.begin(PIN_SCK, PIN_MISO, PIN_MOSI, PIN_CS);
    Serial.println("[1] GPIO + SPI ready");

    Serial.printf("[2] Battery (pre-BLE): %.2f V\n", readBatteryVolts());

    Serial.println("[3] starting BLE radio...");
    NimBLEDevice::init(DEVICE_NAME);
    bleServer = NimBLEDevice::createServer();
    bleServer->setCallbacks(new ServerCallbacks());

    NimBLEService* service = bleServer->createService(SERVICE_UUID);

    for (auto& c : controls) {
        c.characteristic = service->createCharacteristic(
            c.uuid,
            NIMBLE_PROPERTY::READ | NIMBLE_PROPERTY::NOTIFY
        );
        uint16_t initial = readControl(c);
        c.characteristic->setValue(initial);
        c.lastValue = initial;
    }

    service->start();

    NimBLEAdvertising* adv = NimBLEDevice::getAdvertising();
    adv->addServiceUUID(SERVICE_UUID);
    adv->setName(DEVICE_NAME);       
    adv->enableScanResponse(true); 
    bool advOk = adv->start();

    Serial.printf("[4] Advertising as \"%s\" with %u control(s) — start=%s\n",
                  DEVICE_NAME, NUM_CONTROLS, advOk ? "OK" : "FAILED");
}

void loop() {
    updateBatteryLed();
    updateConnLed();

    static uint32_t lastSample = 0;
    if (millis() - lastSample < SAMPLE_MS) return;
    lastSample = millis();

    for (auto& c : controls) {
        uint16_t val = readControl(c);

        bool changed = (c.source == SRC_DIGITAL)
                           ? (val != c.lastValue)
                           : (abs((int)val - (int)c.lastValue) > ADC_DEADBAND);
        if (!changed) continue;

        c.lastValue = val;
        c.characteristic->setValue(val);
        if (clientConnected) {
            c.characteristic->notify();
        }
        // Serial.printf("%s: %u\n", c.name, val);
    }
}

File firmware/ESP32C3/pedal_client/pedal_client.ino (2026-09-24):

// BLE client — runs on the pedalboard unit (XIAO ESP32-C3)
// Scans for the guitar/server, connects, subscribes to every control,
// and forwards a combined snapshot to the Daisy Seed over UART.
//
// Wiring (client side):
//   D6  / GPIO21  ESP_TX        -> Daisy USART1_RX (pin 15)
//   D7  / GPIO20  ESP_RX        <- Daisy USART1_TX (pin 14)
//   D10 / GPIO10  BLUETOOTH_LED -> on while connected to the server
//   shared GND between the ESP32 and the Daisy Seed

#include <NimBLEDevice.h>

// ── UART link to the Daisy Seed ───────────────────────────
static const uint8_t  UART_TX_PIN = D6;   // GPIO21 -> Daisy RX
static const uint8_t  UART_RX_PIN = D7;   // GPIO20 <- Daisy TX
static const uint32_t UART_BAUD   = 115200;
#define DaisySerial Serial1

// ── Connection-status LED ─────────────────────────────────
static const uint8_t  LED_PIN = D10;      // on = connected to server

// ── Match SERVICE_UUID, DEVICE_NAME and characteristic UUIDs to the server ──
static const char* SERVICE_UUID = "a1b2c3d4-0001-0000-0000-000000000000";
static const char* DEVICE_NAME  = "Pedal";

// Order here defines the index used in the UART packet below.
enum ControlIndex { KNOB1, KNOB2, LDR, JOY_X, JOY_Y, SWITCH, NUM_CONTROLS };

struct Control {
    const char*                 name;
    const char*                 uuid;
    NimBLERemoteCharacteristic* characteristic;
};

static Control controls[NUM_CONTROLS] = {
    { "Knob1",  "a1b2c3d4-0001-0000-0000-000000000001", nullptr },
    { "Knob2",  "a1b2c3d4-0001-0000-0000-000000000002", nullptr },
    { "LDR",    "a1b2c3d4-0001-0000-0000-000000000003", nullptr },
    { "JoyX",   "a1b2c3d4-0001-0000-0000-000000000004", nullptr },
    { "JoyY",   "a1b2c3d4-0001-0000-0000-000000000005", nullptr },
    { "Switch", "a1b2c3d4-0001-0000-0000-000000000006", nullptr },
};

// Latest value per control: 0–4095 for the analog inputs, 0/1 for the switch.
static volatile uint16_t values[NUM_CONTROLS] = { 0 };
static volatile bool     dirty = false;   // a value changed and needs forwarding

// ── State ─────────────────────────────────────────────────
static NimBLEClient*  bleClient = nullptr;
static NimBLEAddress  serverAddress;
static bool           connected = false;
static bool           doConnect = false;

// ── UART packet to the Daisy ──────────────────────────────
// Fixed 14-byte frame, sent whenever any control changes:
//   [0]      0xAA   sync
//   [1]      0x55   sync
//   [2..3]   Knob1  uint16 little-endian
//   [4..5]   Knob2
//   [6..7]   LDR
//   [8..9]   JoyX
//   [10..11] JoyY
//   [12]     Switch (0/1)
//   [13]     checksum = XOR of bytes [2..12]
void sendToDaisy() {
    uint8_t pkt[14];
    pkt[0] = 0xAA;
    pkt[1] = 0x55;
    for (int i = 0; i < 5; i++) {
        uint16_t v = values[i];
        pkt[2 + i * 2] = v & 0xFF;
        pkt[3 + i * 2] = v >> 8;
    }
    pkt[12] = values[SWITCH] ? 1 : 0;
    uint8_t cksum = 0;
    for (int i = 2; i <= 12; i++) cksum ^= pkt[i];
    pkt[13] = cksum;
    DaisySerial.write(pkt, sizeof(pkt));
}

// ── Notification callback ─────────────────────────────────
void notifyCallback(NimBLERemoteCharacteristic* pChar, uint8_t* pData, size_t length, bool isNotify) {
    if (length < 2) return;
    uint16_t raw = pData[0] | (pData[1] << 8);

    for (int i = 0; i < NUM_CONTROLS; i++) {
        if (controls[i].characteristic == pChar) {
            values[i] = raw;
            dirty = true;
            break;
        }
    }
}

// ── BLE callbacks ─────────────────────────────────────────
class ClientCallbacks : public NimBLEClientCallbacks {
    void onConnect(NimBLEClient*) override {
        Serial.println("Connected to server");
    }
    void onDisconnect(NimBLEClient*, int reason) override {
        connected = false;
        Serial.printf("Disconnected (reason %d) — scanning again\n", reason);
        NimBLEDevice::getScan()->start(0);
    }
};

class ScanCallbacks : public NimBLEScanCallbacks {
    void onResult(const NimBLEAdvertisedDevice* device) override {
        std::string name = device->getName();
        bool        bySvc  = device->isAdvertisingService(NimBLEUUID(SERVICE_UUID));
        bool        byName = (name == DEVICE_NAME);

        if (!name.empty() || bySvc) {
            Serial.printf("Saw %s  name='%s'  svc=%d\n",
                          device->getAddress().toString().c_str(), name.c_str(), bySvc);
        }

        if (bySvc || byName) {
            Serial.printf("Found server: %s\n", device->getAddress().toString().c_str());
            NimBLEDevice::getScan()->stop();
            serverAddress = device->getAddress();
            doConnect = true;
        }
    }
};

// ── Connection logic ──────────────────────────────────────
bool connectToServer() {
    bleClient = NimBLEDevice::createClient();
    bleClient->setClientCallbacks(new ClientCallbacks());

    if (!bleClient->connect(serverAddress)) {
        Serial.println("Connection failed");
        NimBLEDevice::deleteClient(bleClient);
        bleClient = nullptr;
        return false;
    }

    NimBLERemoteService* service = bleClient->getService(SERVICE_UUID);
    if (!service) {
        Serial.println("Service not found on server");
        bleClient->disconnect();
        return false;
    }

    for (int i = 0; i < NUM_CONTROLS; i++) {
        Control& c = controls[i];
        c.characteristic = service->getCharacteristic(c.uuid);
        if (!c.characteristic) {
            Serial.printf("Characteristic not found: %s\n", c.name);
            continue;
        }

        if (c.characteristic->canRead()) {
            values[i] = c.characteristic->readValue<uint16_t>();
        }

        if (c.characteristic->canNotify()) {
            c.characteristic->subscribe(true, notifyCallback);
        }
    }

    connected = true;       
    dirty = true;          
    return true;
}

// Connection LED: solid when connected, blinks ~2 Hz while scanning/connecting.
void updateConnLed() {
    digitalWrite(LED_PIN, connected ? HIGH : ((millis() / 250) % 2));
}

// ── Arduino entry points ──────────────────────────────────
void setup() {
    Serial.begin(115200);
    DaisySerial.begin(UART_BAUD, SERIAL_8N1, UART_RX_PIN, UART_TX_PIN);

    pinMode(LED_PIN, OUTPUT);
    digitalWrite(LED_PIN, LOW);

    NimBLEDevice::init("");
    NimBLEScan* scan = NimBLEDevice::getScan();
    scan->setScanCallbacks(new ScanCallbacks());
    scan->setActiveScan(true);
    scan->start(0);  // scan indefinitely until the server is found

    Serial.println("Scanning for server...");
}
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
